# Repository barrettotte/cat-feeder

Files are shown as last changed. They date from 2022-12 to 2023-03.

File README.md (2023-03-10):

# cat-feeder

A cat feeder with a web interface

<p align="middle">
  cat-feeder-front
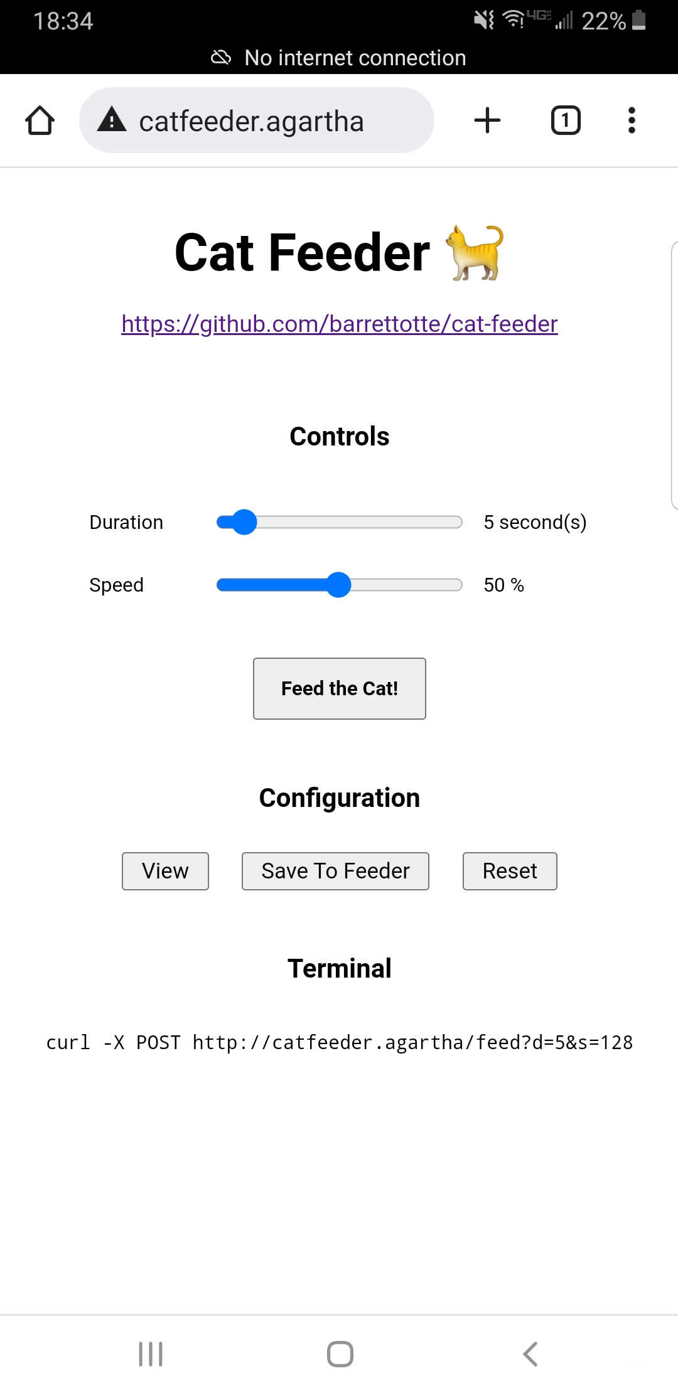
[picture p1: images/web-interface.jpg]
web-interface
  
</p>

## Summary

A cat feeder utilizing a DC motor and an archimedes screw to dispense food.
The feeder hosts a web interface to configure and interact from any device's web browser.
The web interface also generates a corresponding `curl` command, so feed times could potentially be scheduled via cron jobs on another machine.

On the back of the feeder are two LEDs, a button, a power switch, and a 12V DC power jack.
The button is used for manual feeding and can be configured via the feeder's web interface.
The "READY" LED is used to signal to the user that the state machine is in a state where either feeding or
initialization is in progress. When in this state, feed requests are blocked.

This project was put on hold for a couple months due to other projects and 3D printer problems.
I also screwed up the enclosure design at just about every point I could have.
This cat feeder is way too big, hard to assemble, and barely functional.

Additional improvements I wish I did:

- Non-hardcoded WiFi credentials - Have to recompile when changing networks...BAD.
- Serial port access - No way to reconcile errors/bugs via console.
- Don't use soldered jumper wires - Very bad/difficult solder joints, use custom dupont connectors next time.
- Less square nut inserts, More brass thread embedding - terrible to assemble with so many square nuts.
- More compact design - 3D printing large pieces was terrible.
- More modular design - Attempted this, but needs to be more modular for easy printing/assembly.
- Access holes for shaft, etc - Once sealed up, no way to tighten things easily.
- Sturdier motor mount - Seems to flex when pieces of food get jammed.
- Reprint bad enclosure pieces - Should have reprinted large enclosure pieces after resolving 3D printer problems.

But, oh well; Can't win 'em all. Time to move onto something else.
Maybe one day I'll redesign a better cat feeder from scratch when I've learned a lot more on design.

cat-feeder-back

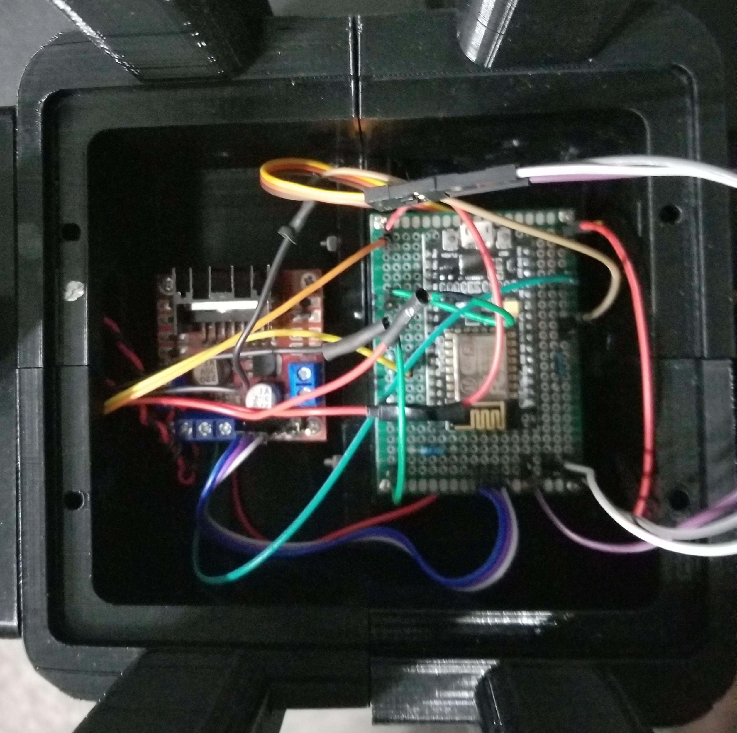
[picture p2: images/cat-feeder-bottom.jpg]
cat-feeder-bottom


## Directories

- [fs/](fs/) - Filesystem uploaded to cat-feeder. Includes configuration JSON and web interface files.
- [fusion360/](fusion360/) - Fusion360 project file, exported models, and incomplete part list.
- [include/](include/) - Configuration for the feeder.
- [inkscape/](inkscape/) - SVGs for back panel of feeder.
- [kicad/](kicad/) - Schematic and electronics parts list.
- [src/](src/) - Backend for the feeder.
- [test/](test/) - Test files and mock backend.

## Setup

- Configure WiFi credentials in `include/secrets.h`
- Upload to ESP8266 with `make upload`
- Set DHCP entry in router for cat-feeder MAC and IP
- Add DNS entry for `catfeeder.agartha`
- Power on, wait for ready LED to turn on (while feeder connects to WiFi)
- Saturate the feeder by running a few long feeds until food falls out of the chute
- Use the web interface at http://catfeeder.agartha to feed the cat

## CAD and Circuit Images

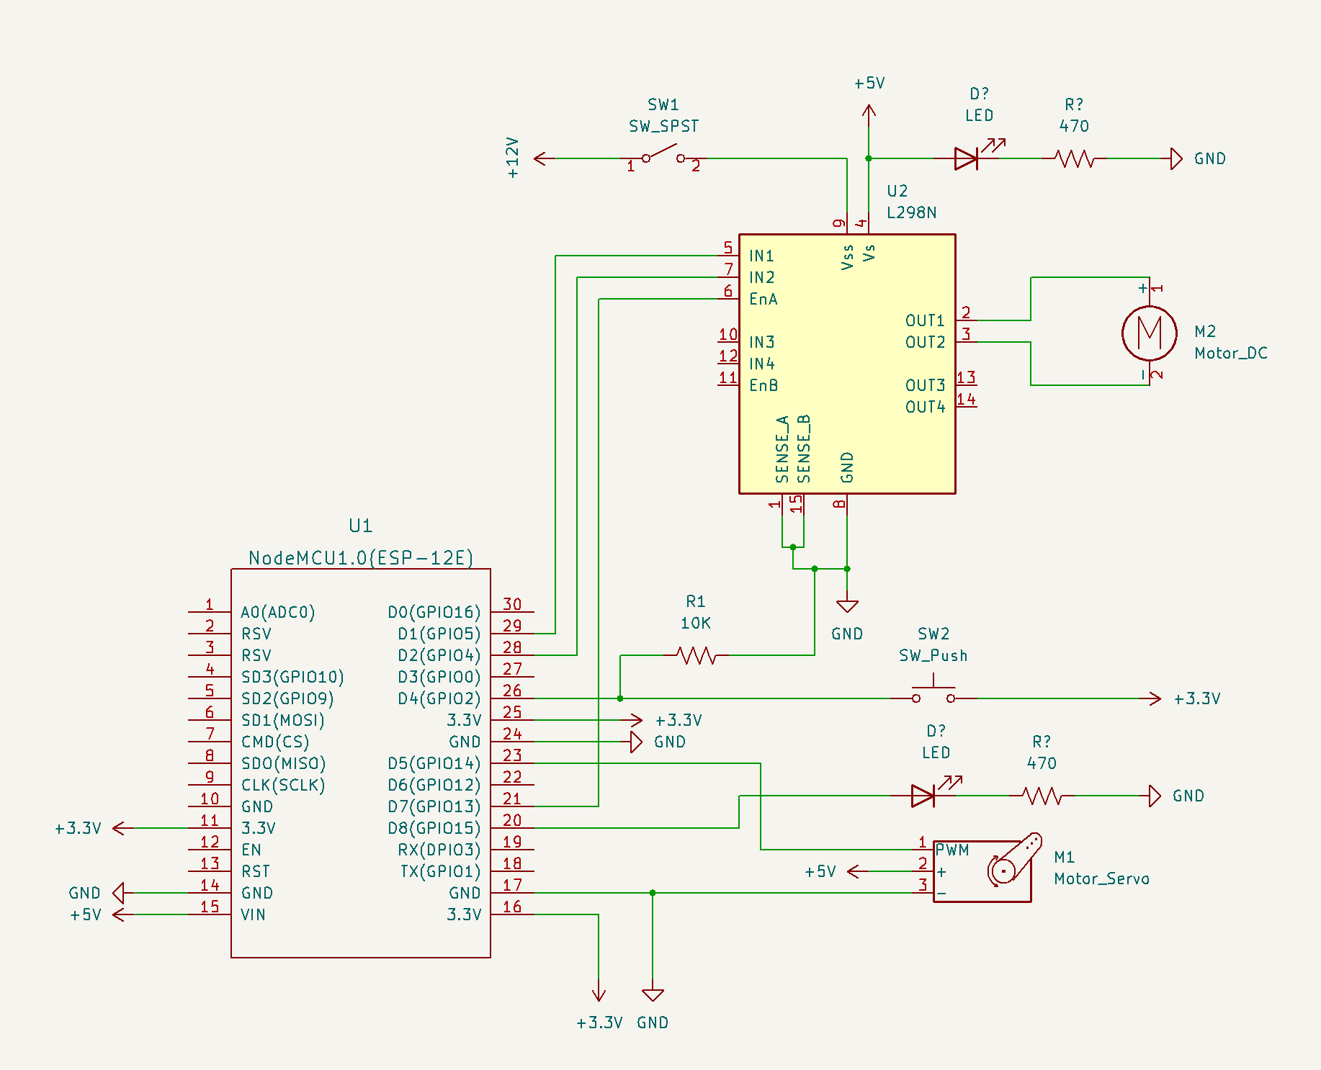
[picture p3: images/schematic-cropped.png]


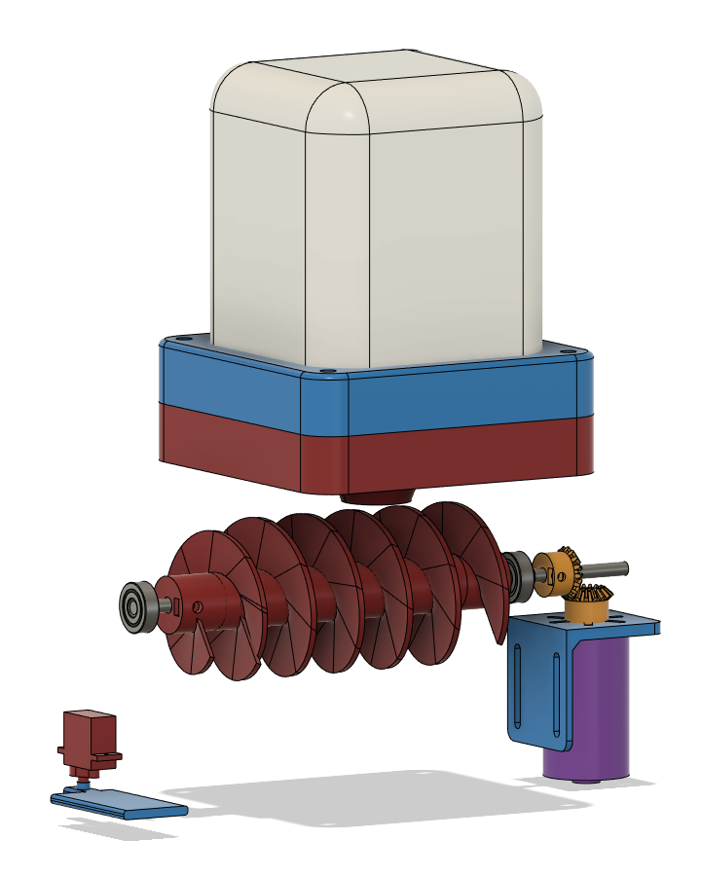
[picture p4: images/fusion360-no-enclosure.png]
fusion360-no-enclosure


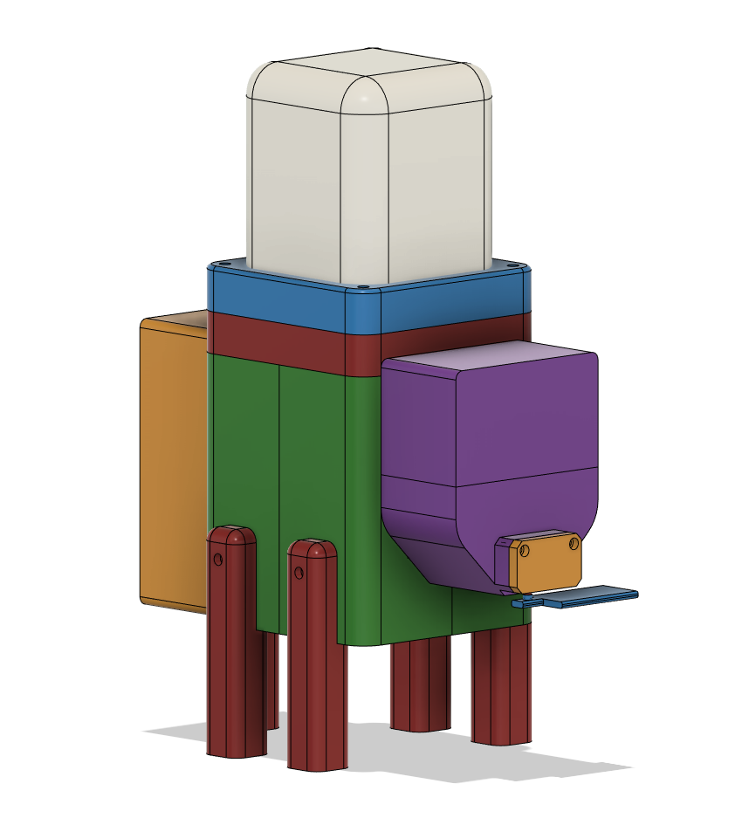
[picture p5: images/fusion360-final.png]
fusion360-final


## Parts

- Electronics parts list is in [kicad/parts.md](kicad/parts.md)
- Incomplete hardware/3D-printed parts list is in [fusion360/parts.md](fusion360/parts.md)

## References

- https://www.youtube.com/watch?v=ICCWvEK6_tg
- https://www.youtube.com/watch?v=7lvErV4l5wQ
- https://microcontrollerslab.com/l298n-dc-motor-driver-module-esp8266-nodemcu/
- https://github.com/jdunmire/kicad-ESP8266

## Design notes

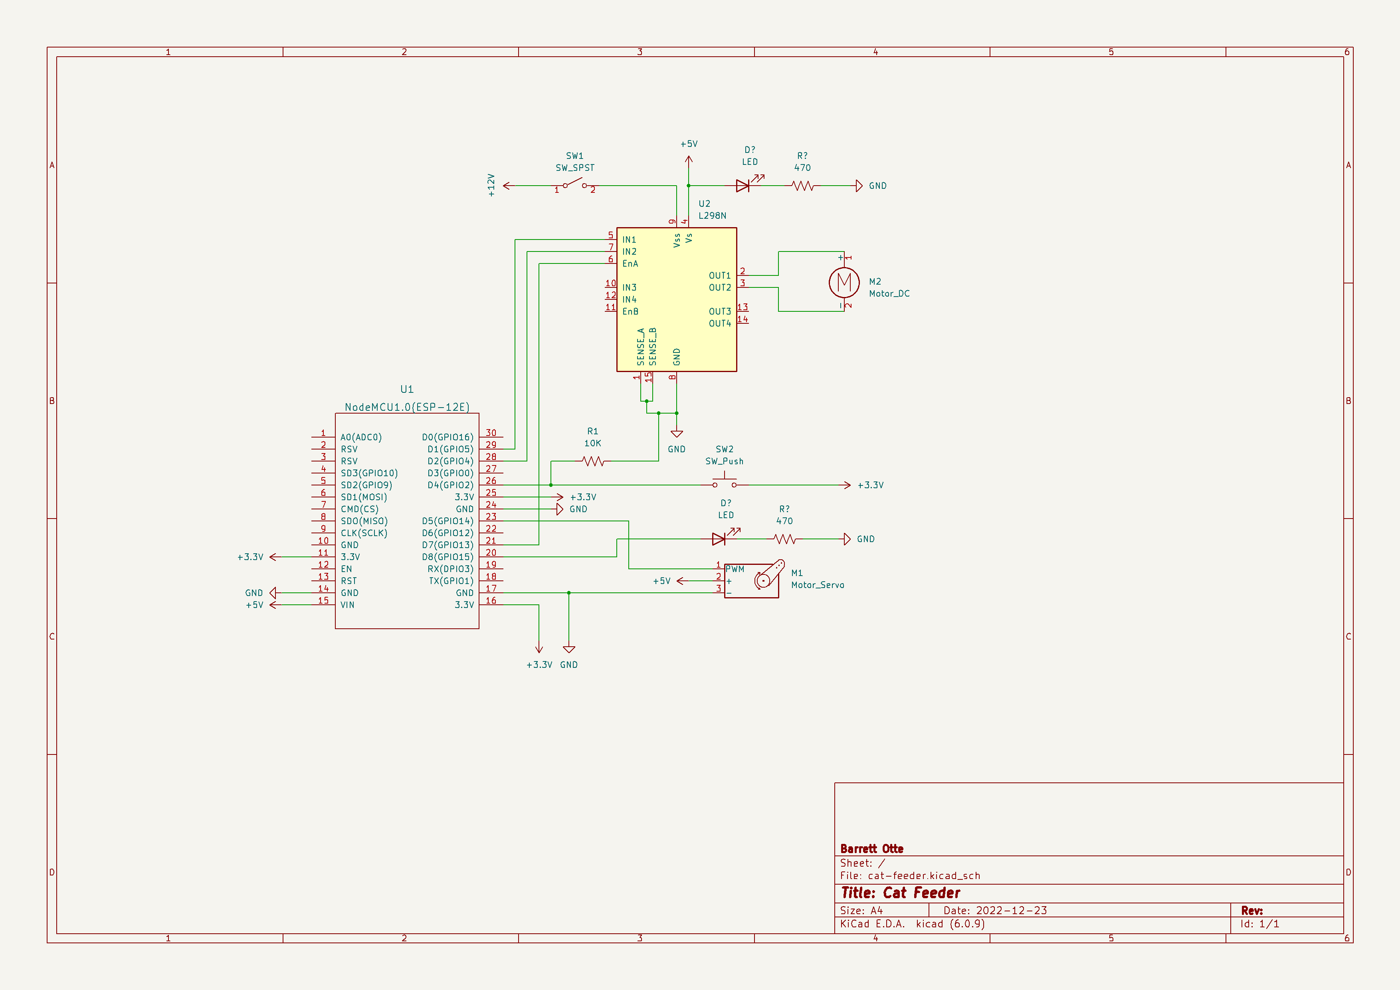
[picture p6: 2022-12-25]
images/schematic.png

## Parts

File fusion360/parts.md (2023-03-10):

# Parts List

## 3D Print

All parts printed with PETG, 0.24mm layer height, and 10-15% infill on Ender 3 Pro.

| Name | Quantity | Print Time |
| --- | --- | --- |
| `archimedes-screw` | 1 | 11h6m |
| `axle-bevel-gear` | 1 | 25m |
| `bearing-adapter` | 2 | 23m (46m) |
| `enclosure-archimedes-back-left` | 1 | 14h19m |
| `enclosure-archimedes-back-right`  | 1 | 15h10m |
| `enclosure-archimedes-bottom-lid`  | 1 | 3h24m |
| `enclosure-archimedes-front-left`  | 1 | 12h38m |
| `enclosure-archimedes-front-right` | 1 | 14h10m |
| `enclosure-chute-bottom` | 1 | 13h50m |
| `enclosure-chute-top` | 1 | 7h27m |
| `enclosure-motor-foot` | 1 | 2h9m |
| `enclosure-motor-lid` | 1 | 2h16m |
| `enclosure-motor` | 1 | 13h46m |
| `hopper-adapter` | 1 | 8h2m |
| `hopper` | 1 | 13h47m |
| `leg` | 4 | 3h26m (13h44m) |
| `motor-bevel-gear` | 1 | 25m |
| `motor-mount` | 1 | 1h50m |
| `servo-arm` | 1 | 41m |
| `servo-cover` | 1 | 33m |
| | | |
| Total Print Time | | TODO: |

## Hardware

| Name | Quantity |
| --- | --- |
| | |

### Notes

- 300x6mm stainless steel rod
- 8x22x7mm 608rs bearing
  - x1 - `enclosure-archimedes` feed through to motor
  - x1 - `enclosure-chute` holds axle
- M4x12mm screw
  - 2x - `motor-mount`
- M4x20mm screw
  - x8 - Connecting `enclosure-archimedes` parts top/bottom
- M4x8mm screw
  - x1 - `motor-bevel-gear` to motor
  - x1 - `axle-bevel-gear` to axle
- M4x12mm screw
  - x2 - `archimedes-screw` to axle
- M4x20mm hex socket head cap screws
  - x4 - Connecting legs to `enclosure-archimedes`
- M4 hex nut
  - x8 - Connecting `enclosure-archimedes` parts top/bottom
  - x4 - Connecting legs to `enclosure-archimedes`
- M4 square nut
  - x2 - `motor-mount`
  - x2 - `axle-bevel-gear` and `motor-bevel-gear`
  - x2 - `enclosure-motor` to `enclosure-archimedes`
  - x2 - `archimedes-screw`
  - x4 - `enclosure-motor-lid`
- M2.5x15+6mm brass standoff
  - x4 - LM298N motor driver mount
  - x2 - Main board mount
- M2.5x6+6mm brass standoff
  - x2 - Main board mount
- M2.5x6mm screw
  - x4 - LM298N motor driver mount
  - x4 - Main board mount
- M3x8mm hex socket button head cap screw
  - x6 - `motor-mount`
- M4x45mm hex socket button head cap screw
  - x4 - `hopper` to `enclosure-archimedes`

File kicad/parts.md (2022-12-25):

# Electronics Parts

| Name | Quantity | Link |
| --- | --- | ---- |
| 12V 1A Power Supply | 1 | https://www.amazon.com/dp/B082D7W362 |
| DC Power Jack Socket Female | 1 | https://www.amazon.com/dp/B098K32L4B |
| DC Motor 12V 30RPM | 1 | https://www.amazon.com/gp/product/B071KFT4P7
| ESP8266 NodeMCU | 1 | https://www.amazon.com/HiLetgo-Internet-Development-Wireless-Micropython/dp/B081CSJV2V/ |
| LM298N Motor Driver | 1 | https://www.amazon.com/Controller-H-Bridge-Stepper-Control-Mega2560/dp/B07WS89781/ |
| Male header pins | | |
| Micro Servo Motor SG90 | 1 | https://www.amazon.com/Miuzei-Helicopter-Airplane-Remote-Control/dp/B07NSVKZP7 |
| Momentary Push Button Switch SPST | 1 | https://www.amazon.com/dp/B08JHVLK84 |
| On/Off Rocker Switch SPST | 1 | https://www.amazon.com/dp/B07SPY9H7Y |
| Protoboard | 1 | |
| Red LED | 2 | |
| Resistor 10KΩ | 1 | |
| Resistor 470Ω | 2 | |

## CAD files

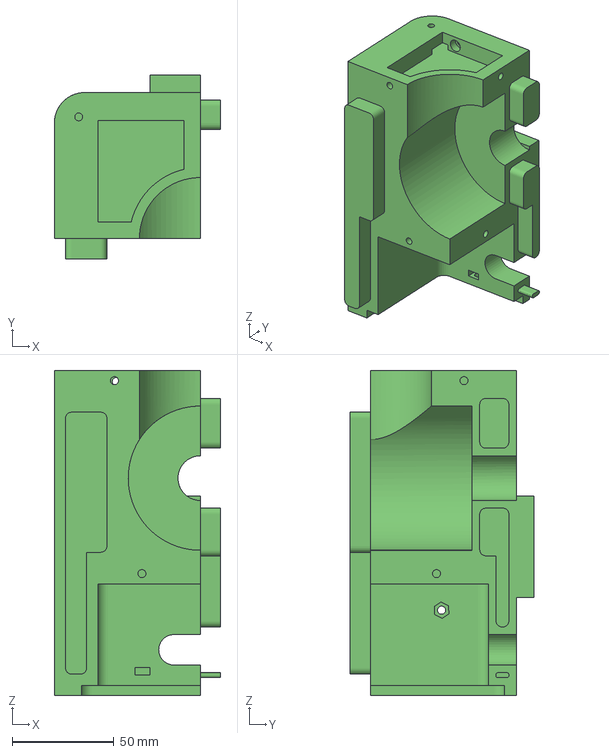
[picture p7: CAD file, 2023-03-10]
fusion360/enclosure-archimedes-back-left.3mf
81.9 x 90.4 x 160.0 mm

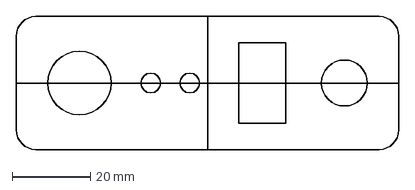
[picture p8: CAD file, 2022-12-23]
inkscape/control-panel.dxf
97.8 x 34.0 mm

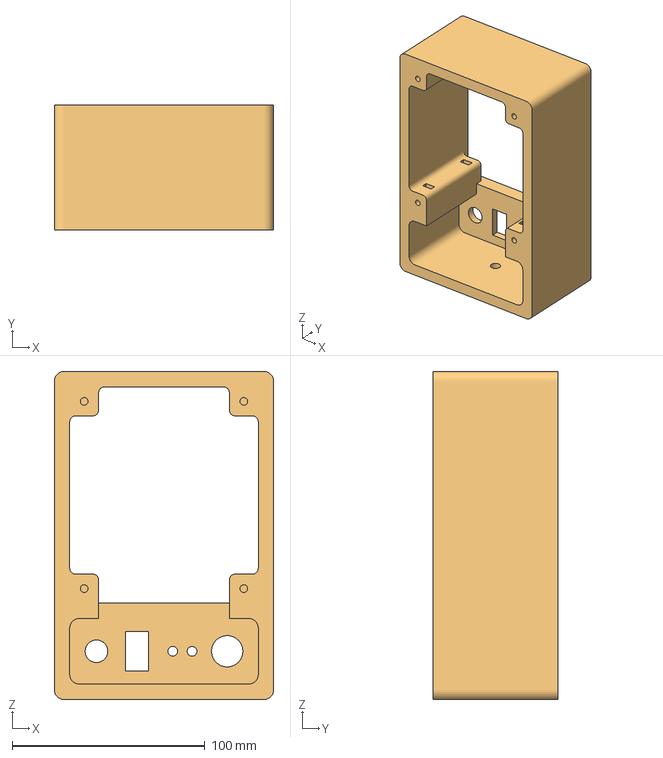
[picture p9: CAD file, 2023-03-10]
fusion360/enclosure-motor.3mf
113.8 x 65.0 x 170.0 mm

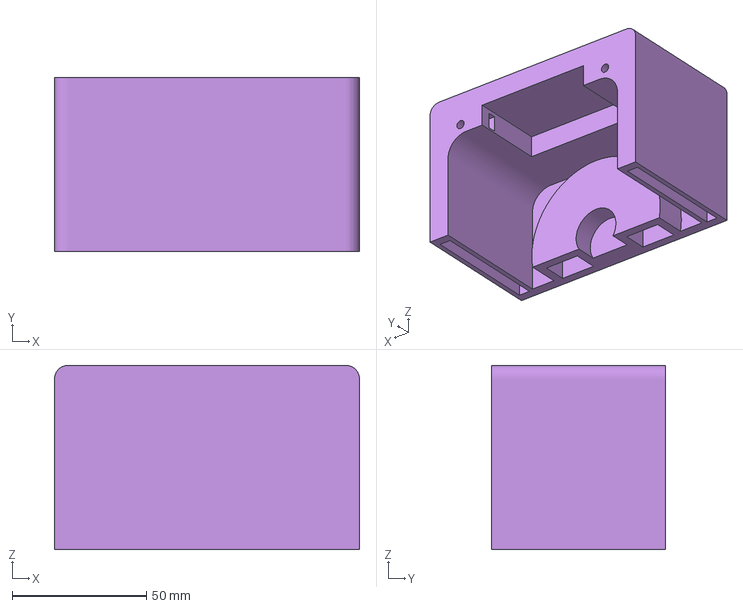
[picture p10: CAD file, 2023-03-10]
fusion360/enclosure-chute-top.3mf
113.8 x 64.8 x 68.7 mm

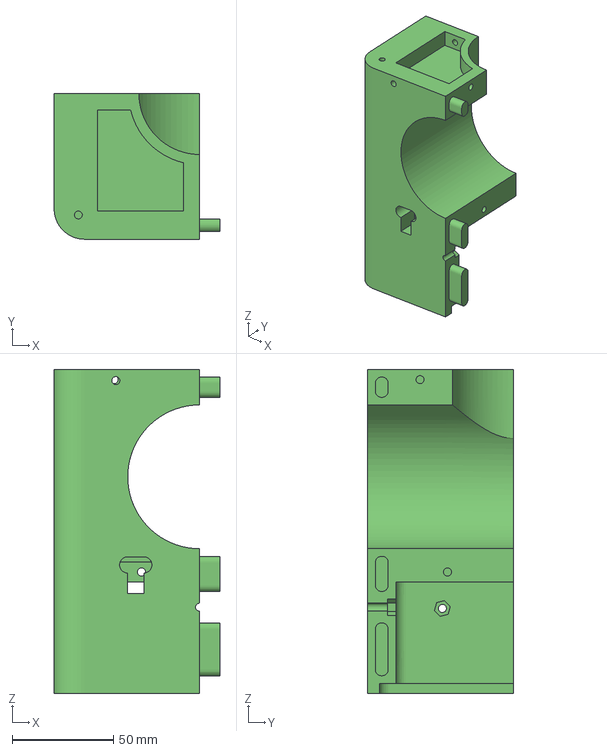
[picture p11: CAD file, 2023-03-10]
fusion360/enclosure-archimedes-front-right.3mf
81.9 x 71.9 x 160.0 mm

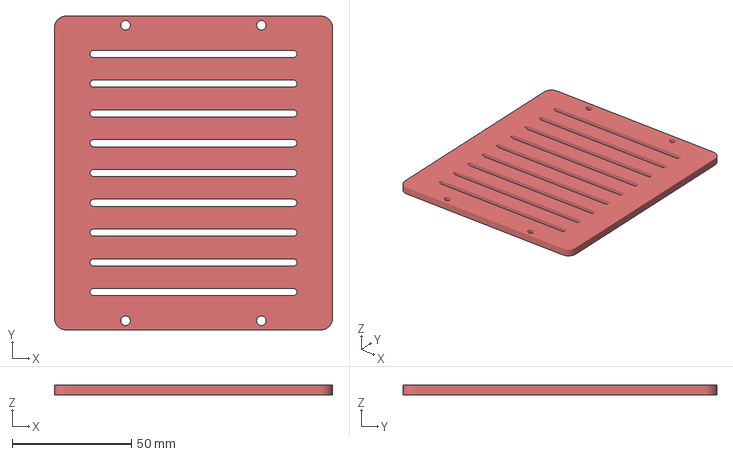
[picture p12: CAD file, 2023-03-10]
fusion360/enclosure-archimedes-bottom-lid.3mf
116.8 x 131.8 x 4.00 mm

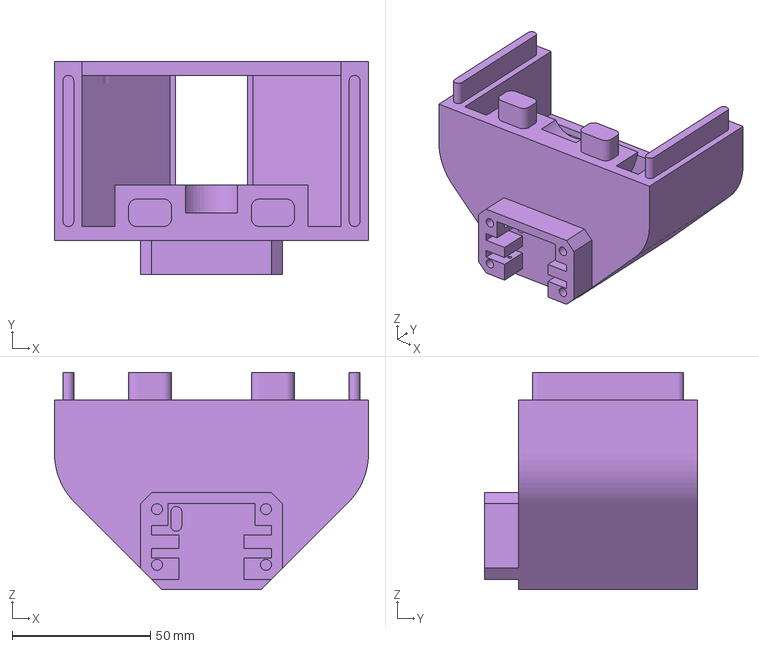
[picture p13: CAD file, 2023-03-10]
fusion360/enclosure-chute-bottom.3mf
113.8 x 77.1 x 78.7 mm

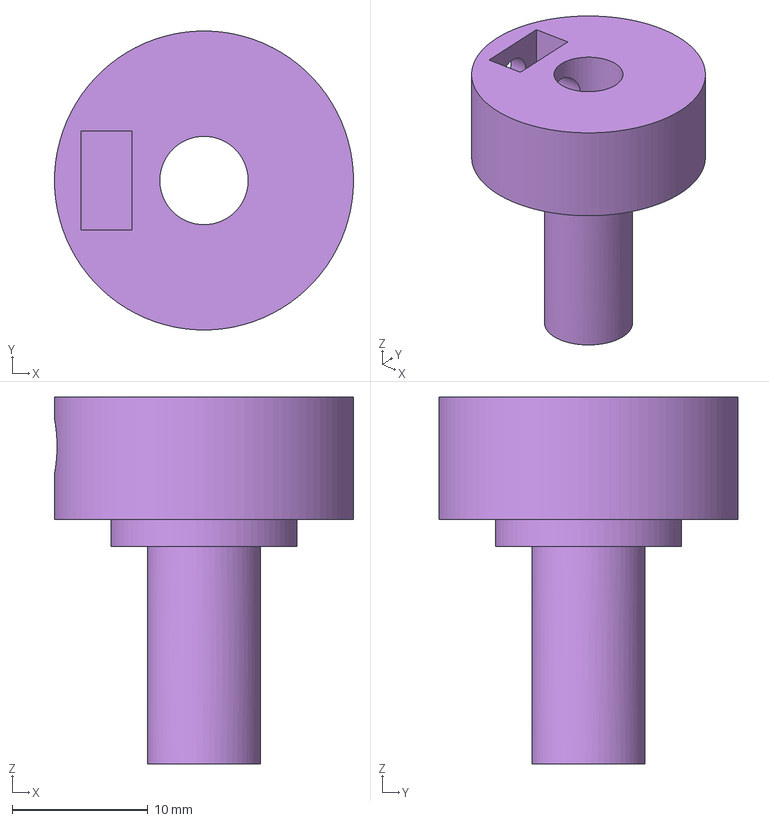
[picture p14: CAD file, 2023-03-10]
fusion360/bearing-adapter.3mf
22.0 x 22.0 x 27.0 mm

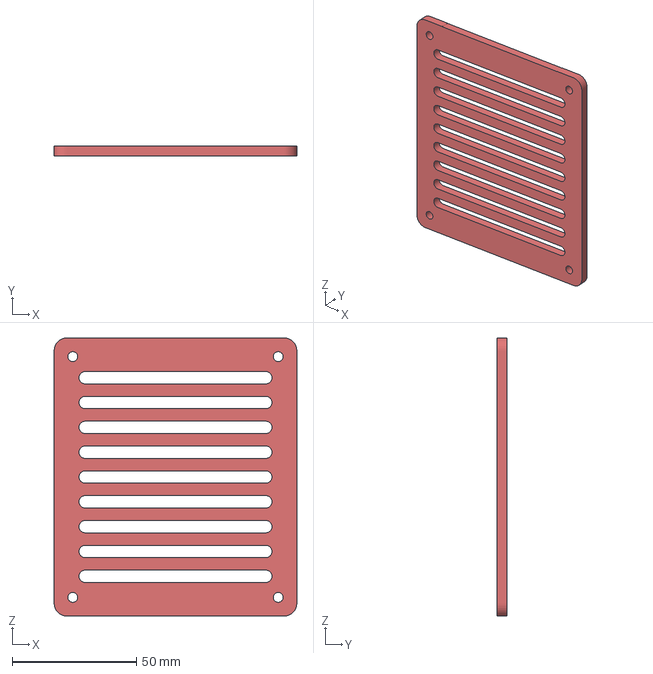
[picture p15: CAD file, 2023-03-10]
fusion360/enclosure-motor-lid.3mf
97.8 x 4.00 x 112.0 mm

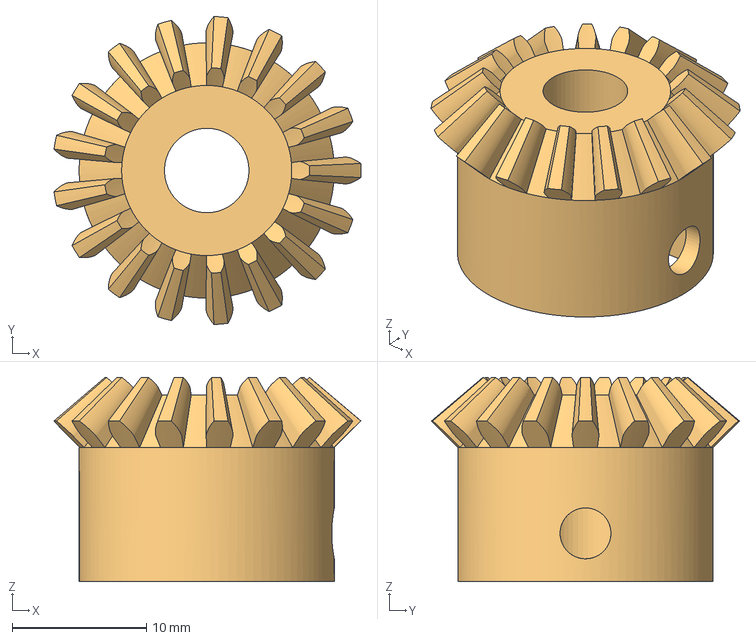
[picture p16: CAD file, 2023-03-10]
fusion360/axle-bevel-gear.3mf
22.9 x 23.0 x 15.2 mm

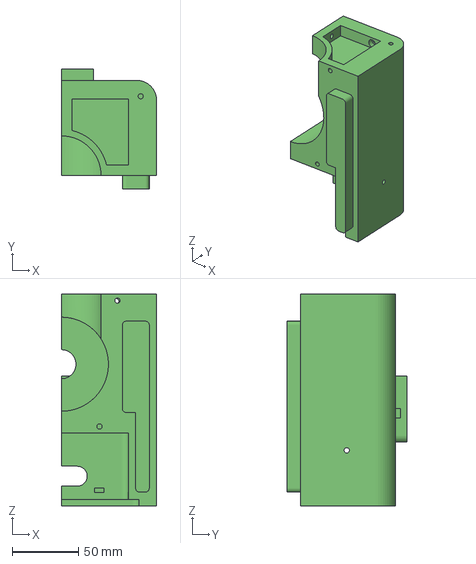
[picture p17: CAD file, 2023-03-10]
fusion360/enclosure-archimedes-back-right.3mf
71.9 x 90.4 x 160.0 mm

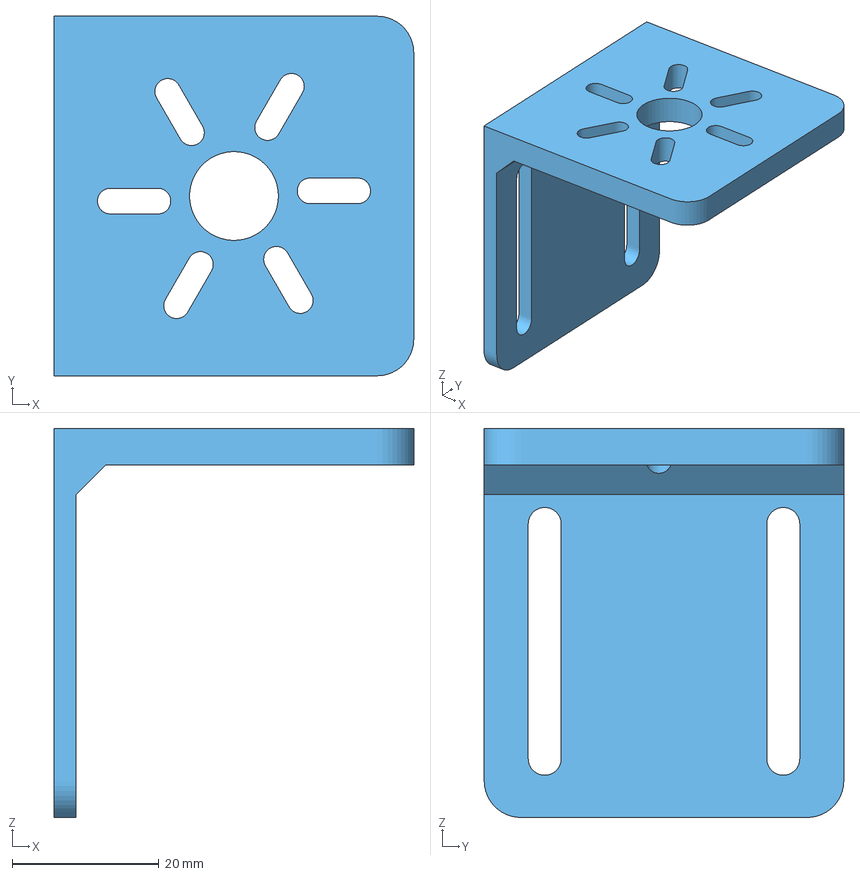
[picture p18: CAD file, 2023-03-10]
fusion360/motor-mount.3mf
49.0 x 49.0 x 53.0 mm

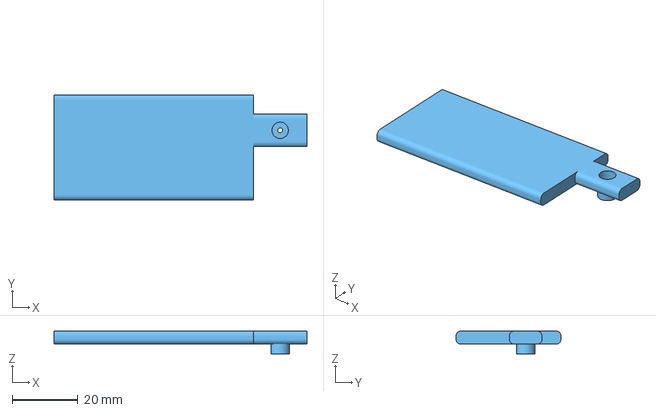
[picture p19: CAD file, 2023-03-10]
fusion360/servo-arm.3mf
77.1 x 32.0 x 7.00 mm

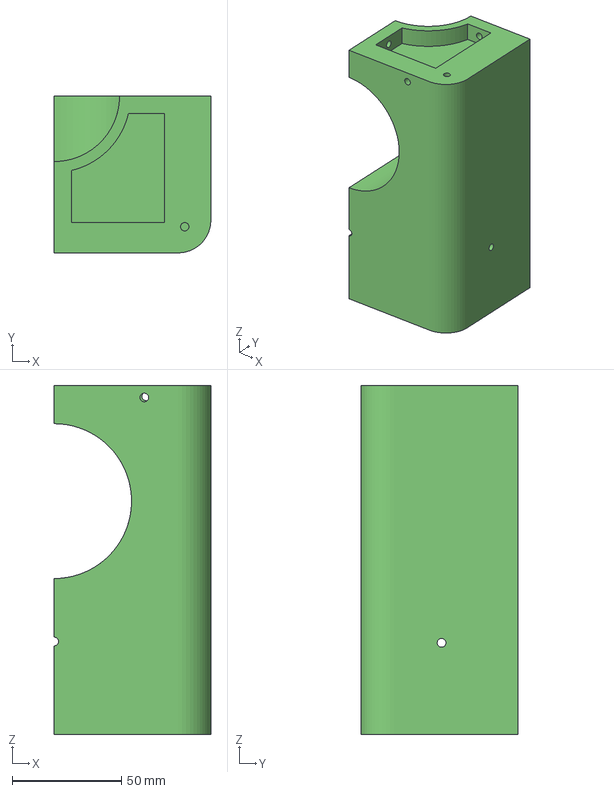
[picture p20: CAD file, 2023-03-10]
fusion360/enclosure-archimedes-front-left.3mf
71.9 x 71.9 x 160.0 mm

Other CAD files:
fusion360/motor-bevel-gear.3mf
fusion360/servo-cover.3mf
fusion360/hopper.3mf
fusion360/hopper-adapter.3mf
fusion360/archimedes-screw.3mf
fusion360/enclosure-motor-foot.3mf
fusion360/leg.3mf

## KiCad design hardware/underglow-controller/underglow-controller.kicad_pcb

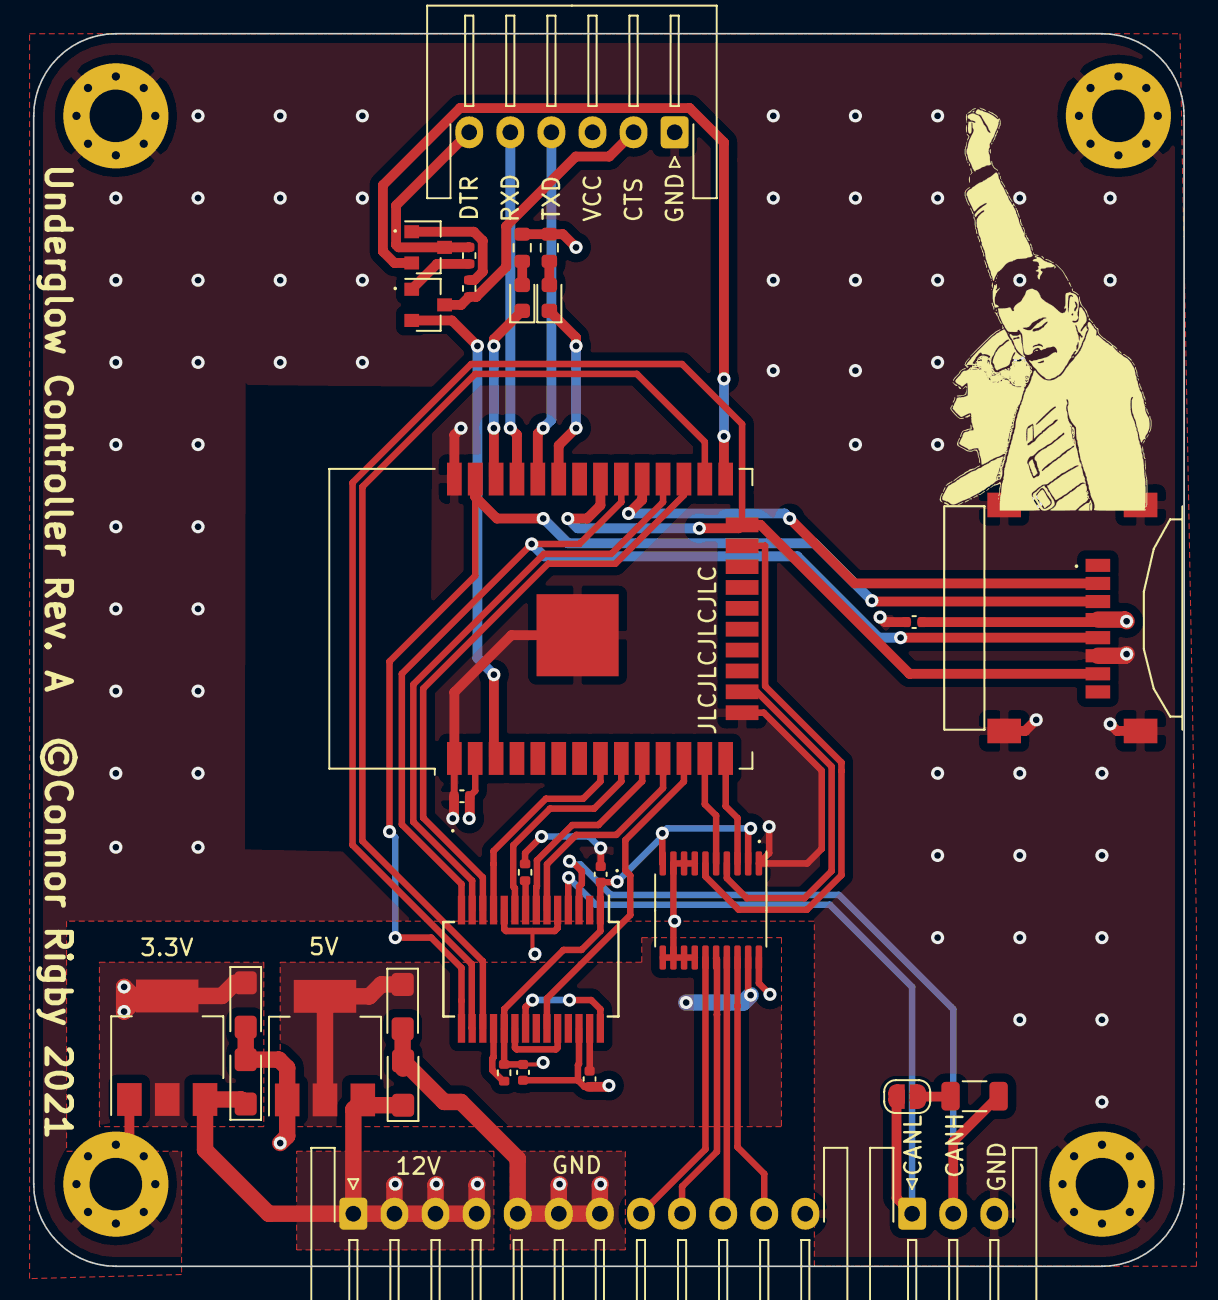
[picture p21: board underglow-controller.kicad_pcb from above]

Board: 4 copper layers, 70.0 x 75.0 mm, 34 parts (0 on the bottom side), 43 nets.

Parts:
C1, C2, C3, C4: 10u; CP_EIA-3216-18_Kemet-A
C5, C6, C7, C8, C9: 100n; C_0402_1005Metric
D1, D2: LED_Small; LED_0603_1608Metric
H1, H2, H3, H4: MountingHole_Pad; MountingHole_3.2mm_M3_Pad_Via
J1: Micro_SD_Card; MOLEX_47219-2001
J2: FTDI; JST_XH_S6B-XH-A-1_1x06_P2.50mm_Horizontal
J3: LEDS; JST_XH_S12B-XH-A-1_1x12_P2.50mm_Horizontal
J4: CAN; JST_XH_S3B-XH-A-1_1x03_P2.50mm_Horizontal
JP1: Jumper_NO_Small; SolderJumper-2_P1.3mm_Open_RoundedPad1.0x1.5mm
Q1, Q2: SS8050; SOT-23
R1, R2, R5, R6: 10k; R_0402_1005Metric
R3, R4: R_Small; R_0603_1608Metric
R7: 120; R_1206_3216Metric
U1: AMS1117-3.3; SOT-223-3_TabPin2
U2: TXS0108EPW; TSSOP-20_4.4x6.5mm_P0.65mm
U3: AMS1117-5.0; SOT-223-3_TabPin2
U4: ESP32-WROOM-32D; ESP32-WROOM-32
U5: MCP25625-x-SS; SSOP-28_5.3x10.2mm_P0.65mm

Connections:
+3V3: C2.1, C5.2, C6.2, C7.2, C8.2, J1.4, R3.1, R4.1, R5.2, U1.2, U2.2, U2.10, U4.2, U5.1, U5.19
+5V: C4.1, C9.2, U2.19, U3.2, U5.27
+12V: C1.1, C3.1, J3.1, J3.2, J3.3, J3.4, U1.3, U3.3
/CANH: J4.1, JP1.1, U5.4
/CANL: J4.2, R7.2, U5.3
/CAN_INT: U4.28, U5.13
/CAN_RX0_BF: U4.27, U5.12
/CAN_RX1_BF: U4.8, U5.11
/CAN_TX0_RTS: U4.12, U5.23
/CAN_TX1_RTS: U4.11, U5.6
/CAN_TX2_RTS: U4.10, U5.7
/FTDI_CTS: J2.2, Q1.3, R2.2
/FTDI_DTR: J2.6, Q2.3, R1.2
/FTDI_RX: J2.5, U4.35
/FTDI_TX: J2.4, U4.34
/GPIO0: Q2.2, U4.25
/LED0: U2.4, U4.16
/LED0_OUT: J3.10, U2.17
/LED1: U2.3, U4.14
/LED1_OUT: J3.11, U2.18
/LED2: U2.5, U4.13
/LED2_OUT: J3.9, U2.16
/LED3: U2.6, U4.23
/LED3_OUT: J3.8, U2.15
/RESET: Q1.2, U4.3
/SD_CLK: J1.5, U4.30, U5.14
/SD_CMD: J1.3, U4.37, U5.15
/SD_D0: J1.7, U4.24, U4.31, U5.16
/SD_D3: J1.2, U4.29
/SPI_CS: U4.26, U5.17
/STATUS0: D1.1, U4.33
/STATUS1: D2.1, U4.36
/XTAL_OUT: U4.9, U5.9
GND: C1.2, C2.2, C3.2, C4.2, C5.1, C6.1, C7.1, C8.1, C9.1, H1.1, H2.1, H3.1, H4.1, J1.6, J1.G1, J1.G2, J1.G3, J1.G4, J2.1, J3.5, J3.6, J3.7, J3.12, J4.3, R6.2, U1.1, U2.1, U2.7, U2.8, U2.9, U2.11, U2.12, U2.13, U2.14, U2.20, U3.1, U4.1, U4.15, U4.38, U4.39, U5.5, U5.10, U5.26
unnamed: D1.2, R3.2
unnamed: D2.2, R4.2
unnamed: JP1.2, R7.1
unnamed: Q1.1, R1.1
unnamed: Q2.1, R2.1
unnamed: R5.1, U5.18
unnamed: R6.1, U5.8
unnamed: U5.20, U5.24
unnamed: U5.21, U5.28

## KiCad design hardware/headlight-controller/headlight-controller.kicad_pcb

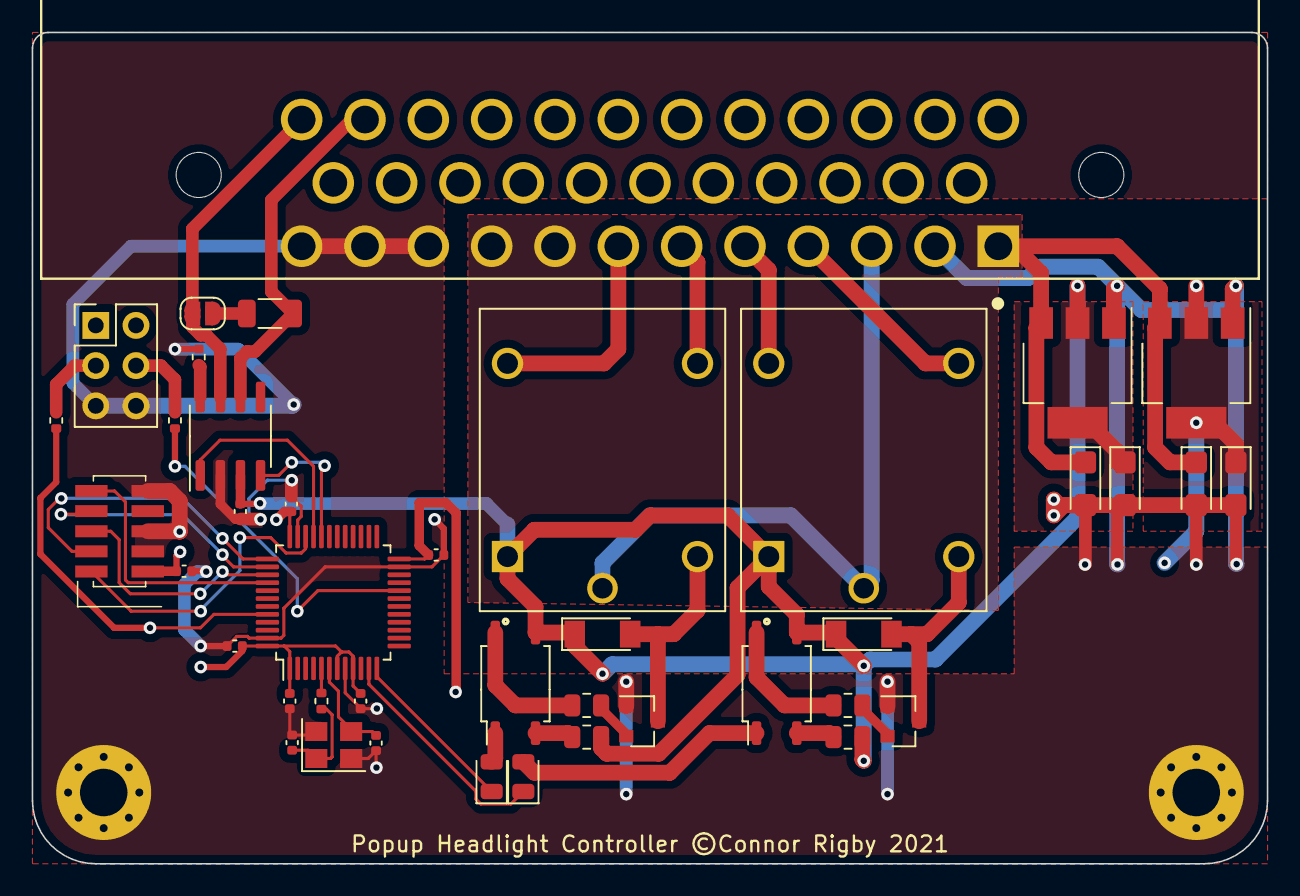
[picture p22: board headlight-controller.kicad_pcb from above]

Board: 2 copper layers, 78.0 x 52.5 mm, 43 parts (0 on the bottom side), 39 nets.

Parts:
C1, C2, C3, C7: 10u; CP_EIA-3216-18_Kemet-A
C4, C6: 12p; C_0402_1005Metric
C5, C8, C9, C10, C11, C12, C13: 100n; C_0402_1005Metric
D1, D2: RED; LED_0805_2012Metric
D3, D4: ZMM5V6; D_MiniMELF
H1, H2: MountingHole_Pad; MountingHole_3mm_Pad_Via
J1: Conn_ARM_JTAG_SWD_10; 20021221-00010C4LF
J2: 776180-1; TE_776180-1
J3: BOOT; PinHeader_2x03_P2.54mm_Vertical
JP1: Jumper_NO_Small; SolderJumper-2_P1.3mm_Open_RoundedPad1.0x1.5mm
K1, K2: SRD-05VDC-SL-C; RELAY_SRD-05VDC-SL-C
Q1, Q2: S8050; SOT-23
R1, R2: 1k; R_0805_2012Metric
R3, R4: 510; R_0805_2012Metric
R5: 120; R_1206_3216Metric
R6, R8: 100K; R_0402_1005Metric
R7: 1M; R_0402_1005Metric
R9: 4.7k; R_0402_1005Metric
U1: AMS1117-3.3; SOT-223-3_TabPin2
U2: AMS1117-5.0; SOT-223-3_TabPin2
U3: STM32F103C8Tx; LQFP-48_7x7mm_P0.5mm
U4: MCP2551-I-SN; SOIC-8_3.9x4.9mm_P1.27mm
U5, U6: EL357N(B)(TA)-G; SOP-4_4.1x4.4mm_P2.54mm
Y1: Crystal_GND24_Small; Crystal_SMD_3225-4Pin_3.2x2.5mm

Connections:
+3V3: C2.1, C5.1, C8.1, C9.1, C10.1, C11.1, C12.1, J1.1, J3.1, J3.2, U1.2, U3.1, U3.7, U3.9, U3.24, U3.36, U3.48
+5V: C7.1, C13.1, D3.1, D4.1, K1.A1, K2.A1, R1.2, R2.2, U2.2, U4.3, U5.3, U6.3
+12V: C1.1, C3.1, J2.1, J2.8, J2.9, U1.3, U2.3
/BOOT0: R6.2, U3.44
/BOOT1: R8.1, U3.20
/CANH: J2.35, JP1.1, U4.7
/CANL: J2.34, R5.1, U4.6
/CAN_RX: U3.32, U4.4
/CAN_TX: U3.33, U4.1
/HL1_DN: J2.7, K1.NC
/HL1_IN: D1.1, U3.12
/HL1_UP: J2.6, K1.NO
/HL2_DN: J2.5, K2.NC
/HL2_IN: D2.1, U3.11
/HL2_UP: J2.4, K2.NO
/HL_COM: J2.3, K1.COM, K2.COM
/HSE_IN: R7.1, U3.5
/HSE_OUT: C6.1, U3.6, Y1.3
/JNTRST: J1.10, U3.40
/SWDCLK: J1.4, U3.37
/SWDIO: J1.2, U3.34
/SWO: J1.6, U3.39
/TDI: J1.8, U3.38
GND: C1.2, C2.2, C3.2, C4.2, C5.2, C6.2, C7.2, C8.2, C9.2, C10.2, C11.2, C12.2, C13.2, H1.1, H2.1, J1.3, J1.5, J1.9, J2.2, J2.10, J2.11, J2.12, J3.5, J3.6, Q1.1, Q2.1, R9.1, U1.1, U2.1, U3.8, U3.23, U3.35, U3.47, U4.2, Y1.2, Y1.4
unnamed: C4.1, R7.2, Y1.1
unnamed: D1.2, U5.1
unnamed: D2.2, U6.1
unnamed: D3.2, K1.A2, Q1.3
unnamed: D4.2, K2.A2, Q2.3
unnamed: J3.3, R6.1
unnamed: J3.4, R8.2
unnamed: JP1.2, R5.2
unnamed: Q1.2, R3.1
unnamed: Q2.2, R4.1
unnamed: R1.1, U5.2
unnamed: R2.1, U6.2
unnamed: R3.2, U5.4
unnamed: R4.2, U6.4
unnamed: R9.2, U4.8

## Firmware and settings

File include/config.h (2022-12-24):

#pragma once

#include "secrets.h"

#define CONFIG_PATH "/config.json"

#define BUTTON_PIN D4
#define READY_PIN D8

#define SERVO_PIN D5
#define MOTOR_EN_PIN D7
#define MOTOR_IN1_PIN D1
#define MOTOR_IN2_PIN D2

#define HTTP_PORT 80
#define BUFFER_SIZE 64
#define DEBOUNCE_MS 250

#define DEFAULT_DURATION 10
#define MAX_DURATION 60
#define DEFAULT_SPEED 128
#define MAX_SPEED 255

#define SERVO_OPEN 90
#define SERVO_CLOSE 0

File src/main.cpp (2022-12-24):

#include <Arduino.h>
#include <ArduinoJson.h>
#include <AsyncJson.h>
#include <ESP8266WiFi.h>
#include <ESPAsyncTCP.h>
#include <ESPAsyncWebServer.h>
#include <LittleFS.h>
#include <memory.h>
#include <Servo.h>

#include "config.h"

#define ERROR_HALT(s) Serial.println(s); while(1) {}

struct feedConfig {
    uint8_t duration;
    uint8_t speed;
};

struct feederState {
    bool trigger;
    uint8_t servoAngle;
    uint8_t motorDuration;
    uint8_t motorSpeed;
    bool motorEn;
};

struct inputTimer {
    bool trigger;
    unsigned long currentMs;
    unsigned long prevMs;
};

/*** globals ***/

const int configJsonCapacity = JSON_OBJECT_SIZE(2); // 1 object with 2 members

Servo servo;
AsyncWebServer server(HTTP_PORT);
auto feeder = std::unique_ptr<feederState>(new feederState);
auto config = std::unique_ptr<feedConfig>(new feedConfig);
auto buttonTimer = std::unique_ptr<inputTimer>(new inputTimer);

/*** utils ***/

void setServoAngle(uint8_t angle) {
    servo.write(angle);
    feeder->servoAngle = angle;
    Serial.printf("Servo: angle=%d\n", angle);
}

void moveServo(bool open) {
    setServoAngle(open ? SERVO_OPEN : SERVO_CLOSE);
    delay(50);
}

void setMotor(bool enabled, uint8_t speed) {
    speed = constrain(speed, 0, MAX_SPEED);
    digitalWrite(MOTOR_IN1_PIN, LOW);

    if (enabled) {
        digitalWrite(MOTOR_IN2_PIN, HIGH);
        analogWrite(MOTOR_EN_PIN, speed);
    } else {
        digitalWrite(MOTOR_IN2_PIN, LOW);
    }
    feeder->motorEn = enabled;
    feeder->motorSpeed = speed;
    Serial.printf("Motor: en=%d,speed=%d\n", enabled, speed);
    delay(50);
}

uint8_t loadConfig() {
    int result = 0;
    char buffer[BUFFER_SIZE];

    File f = LittleFS.open(CONFIG_PATH, "r");
    f.readBytes(buffer, BUFFER_SIZE);

    StaticJsonDocument<configJsonCapacity> data;
    DeserializationError err = deserializeJson(data, buffer);

    if (err) {
        Serial.printf("JSON deserialize failed with code");
        Serial.println(err.f_str());
        result = -1;
    } else {
        config->duration = constrain(data["duration"], 0, MAX_DURATION);
        config->speed = constrain(data["speed"], 0, MAX_SPEED);
    }
    f.close();
    delay(50);
    return result;
}

void saveConfig() {
    File f = LittleFS.open(CONFIG_PATH, "w");
    f.printf("{\"duration\":%d,\"speed\":%d}", config->duration, config->speed);
    f.close();
    delay(50);
}

void resetState() {
    setMotor(false, DEFAULT_SPEED);
    moveServo(false);
    feeder->trigger = false;
}

void feed(uint8_t duration, uint8_t speed) {
    Serial.printf("Feeding with duration=%d,speed=%d\n", duration, speed);
    digitalWrite(READY_PIN, LOW);

    // ensure servo closed
    moveServo(false);
    delay(500);

    // open chute
    moveServo(true);
    delay(500);

    // run motor for duration
    setMotor(true, speed);
    delay(duration * 1000); // secs to ms
    setMotor(false, 0);
    delay(500);

    // close chute
    moveServo(false);
    delay(500);

    digitalWrite(READY_PIN, HIGH);
}

/*** handlers ***/

void handleManualServo(AsyncWebServerRequest* req) {
    if (feeder->trigger) {
        req->send(503);
    } else {
        setServoAngle(req->arg("a").toInt());
        req->send(200);
    }
}

void handleManualMotor(AsyncWebServerRequest* req) {
    if (feeder->trigger) {
        req->send(503);
    } else {
        setMotor(req->arg("en").toInt(), req->arg("s").toInt());
        req->send(200);
    }
}

void handleGetConfig(AsyncWebServerRequest* req) {
    char buffer[BUFFER_SIZE];
    sprintf(buffer, "{\"duration\":%d,\"speed\":%d}", config->duration, config->speed);
    req->send_P(200, "application/json;charset=utf-8", buffer);
}

void handleSetConfig(AsyncWebServerRequest* req, JsonVariant& json) {
    StaticJsonDocument<configJsonCapacity> data;
    data = json.as<JsonObject>();
    config->duration = constrain(data["duration"], 0, MAX_DURATION);
    config->speed = constrain(data["speed"], 0, MAX_SPEED);
    saveConfig();

    Serial.printf("Set config: duration=%d,speed=%d\n", config->duration, config->speed);
    req->send(200);
}

void handleReset(AsyncWebServerRequest* req) {
    resetState();
    config->duration = DEFAULT_DURATION;
    config->speed = DEFAULT_SPEED;
    saveConfig();

    Serial.println("Reset config and state");
    req->send(200);
}

void handleFeed(AsyncWebServerRequest* req) {
    uint8_t duration = config->duration;
    uint8_t speed = config->speed;

    // if passed, override config temporarily
    if (req->hasParam("d")) {
        duration = constrain(req->arg("d").toInt(), 0, MAX_DURATION);
    }
    if (req->hasParam("s")) {
        speed = constrain(req->arg("s").toInt(), 0, MAX_SPEED);
    }
    feeder->motorDuration = duration;
    feeder->motorSpeed = speed;
    feeder->trigger = true;

    req->send_P(200, "text/plain;charset=utf-8", "Fed the cat!");
}

/*** initialization ***/

void initSerial() {
    Serial.begin(9600);
    Serial.println();

    for(uint8_t t = 3; t > 0; t--){
        Serial.printf("WAIT %d...\n", t);
        Serial.flush();
        delay(500);
    }
    Serial.println("\n* * * START * * *");
}

void initWifi() {
    WiFi.mode(WIFI_STA);
    WiFi.begin(_WIFI_SSID, _WIFI_PASS);
    Serial.printf("Connecting to WiFi [%s]", _WIFI_SSID);

    while (WiFi.status() != WL_CONNECTED) {
        delay(1000);
        Serial.printf(".");
    }
    Serial.println("IP => " + WiFi.localIP().toString());
}

void initConfig() {
    config->duration = DEFAULT_DURATION;
    config->speed = DEFAULT_SPEED;
    if (loadConfig()) {
        ERROR_HALT("Error occurred while loading initial config.");
    }
}

void initServo() {
    if (servo.attach(SERVO_PIN) == 0) {
        ERROR_HALT("Error occurred while attaching to servo.");
    }
    moveServo(false);
}

void initMotor() {
    pinMode(MOTOR_EN_PIN, OUTPUT);
    pinMode(MOTOR_IN1_PIN, OUTPUT);
    pinMode(MOTOR_IN2_PIN, OUTPUT);
    setMotor(false, DEFAULT_SPEED);
}

void initFs() {
    if (!LittleFS.begin()) {
        ERROR_HALT("Error occurred while mounting LittleFS.");
    }
    delay(50);
}

void initServer() {
    server.onNotFound([](AsyncWebServerRequest* req) {
        req->send_P(404, "text/plain;charset=utf-8", "Page not found.");
    });
    server.on("/", HTTP_GET, [](AsyncWebServerRequest* req) {
        req->send(LittleFS, "/index.html", "text/html");
    });
    server.on("/styles.css", HTTP_GET, [](AsyncWebServerRequest* req) {
        req->send(LittleFS, "/styles.css", "text/css");
    });
    server.on("/cat-feeder.js", HTTP_GET, [](AsyncWebServerRequest* req) {
        req->send(LittleFS, "/cat-feeder.js", "application/javascript");
    });
    server.on("/config.json", HTTP_GET, [](AsyncWebServerRequest* req) {
        req->send(LittleFS, "/config.json", "application/json");
    });

    server.on("/servo", HTTP_POST, handleManualServo);
    server.on("/motor", HTTP_POST, handleManualMotor);
    server.on("/config", HTTP_GET, handleGetConfig);
    server.addHandler(new AsyncCallbackJsonWebHandler("/config", handleSetConfig));
    server.on("/reset", HTTP_POST, handleReset);
    server.on("/feed", HTTP_POST, handleFeed);

    server.begin();
    Serial.printf("Server listening on port %d...\n", HTTP_PORT);
}

/*** main ***/

void setup() {
    pinMode(BUTTON_PIN, INPUT);
    pinMode(READY_PIN, OUTPUT);
    digitalWrite(READY_PIN, LOW);
    
    initSerial();
    initWifi();
    initFs();
    initConfig();

    initServo();
    initMotor();
    initServer();

    feeder->trigger = false;
    buttonTimer->trigger = false;
    delay(1000);

    digitalWrite(READY_PIN, HIGH);
    Serial.println("Setup Done.");
}

void loop() {

    // check for debounced button press
    buttonTimer->currentMs = millis();
    if ((buttonTimer->currentMs - buttonTimer->prevMs) > DEBOUNCE_MS && digitalRead(BUTTON_PIN) == HIGH) {
        buttonTimer->trigger = true;
        buttonTimer->prevMs = buttonTimer->currentMs;
        Serial.println("Button pressed.");
    }

    if (buttonTimer->trigger) {
        if (!feeder->trigger) {
            feeder->motorDuration = config->duration;
            feeder->motorSpeed = config->speed;
            feeder->trigger = true;
            Serial.println("Triggering feed via button press.");
        } else {
            Serial.println("Feeder is already triggered. Button press ignored.");
        }
        buttonTimer->trigger = false;
    } 

    if (feeder->trigger) {
        feed(feeder->motorDuration, feeder->motorSpeed);
        feeder->trigger = false;
        delay(250);
    }
}

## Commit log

2022-12-17 add motor and servo
2022-12-22 add missing config save
    [main.cpp]
2022-12-23 fixes button firing bug
    [config.h, main.cpp]
2022-12-23 add schematic
    [cat-feeder.kicad_pcb, cat-feeder.kicad_sch]
2022-12-23 add small 3d printed parts
    [axle-bevel-gear.3mf, bearing-adapter.3mf, enclosure-motor-foot.3mf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]
2022-12-23 add control panel svg
    [control-panel.dxf]
2022-12-23 new layout of control panel
    [control-panel.dxf]
2022-12-24 add ready LED
2022-12-24 add ready and power LEDs to schematic
    [cat-feeder.kicad_sch]
2022-12-25 change LED resistors to 470 ohm
    [cat-feeder.kicad_sch]
2022-12-25 fixes incorrect button wiring in schematic
    [cat-feeder.kicad_sch]
2023-03-10 final 3d printed export
    [archimedes-screw.3mf, axle-bevel-gear.3mf, bearing-adapter.3mf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]
